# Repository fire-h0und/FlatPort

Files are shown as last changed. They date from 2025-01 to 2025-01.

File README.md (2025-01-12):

# FlatPort
Teensy 2.0 Risc-V dropin Arduino promicro lookalike with special features. The chip I used is [GD32 VF 103 CBT6](https://www.gigadevice.com/product/mcu/mcus-product-selector/gd32vf103cbt6) from Giga Device. 

It has a in-plane Type-C USB receptacle - it does not show much but it doubles as a full featured Type-C port - in this case a reversible USB 2.0 spec port only.

It also features in-plane Reset and Boot0 tasters - they are shorted by touching with a pointy conductive/metal object.<br>
  Do note they are not to be touched mutually by a same metal object: one shorts pin Boot0 to ground the other pulls the reset pin to Vcc.<br>
  In effect this means one of the contacts is gound and the other is Vcc - shorting them mutually would blow the fuse!

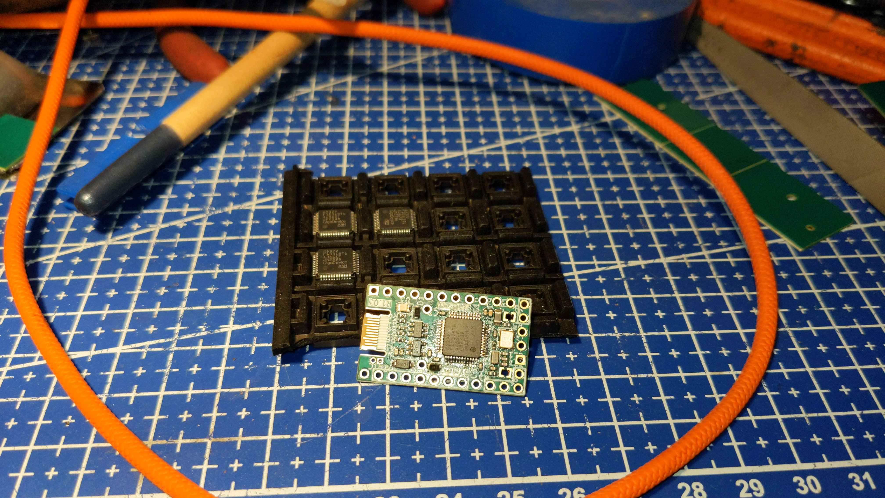
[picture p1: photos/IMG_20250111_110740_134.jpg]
Top view assembled A top view of the FlatPort R1.03


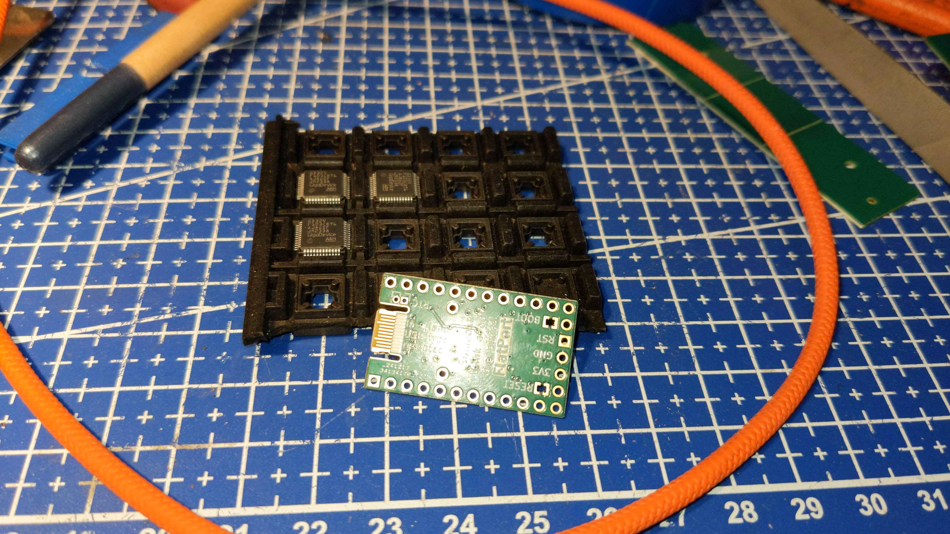
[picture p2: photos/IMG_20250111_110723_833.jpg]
Bottom View A clumsy lit back view of the FlatPort


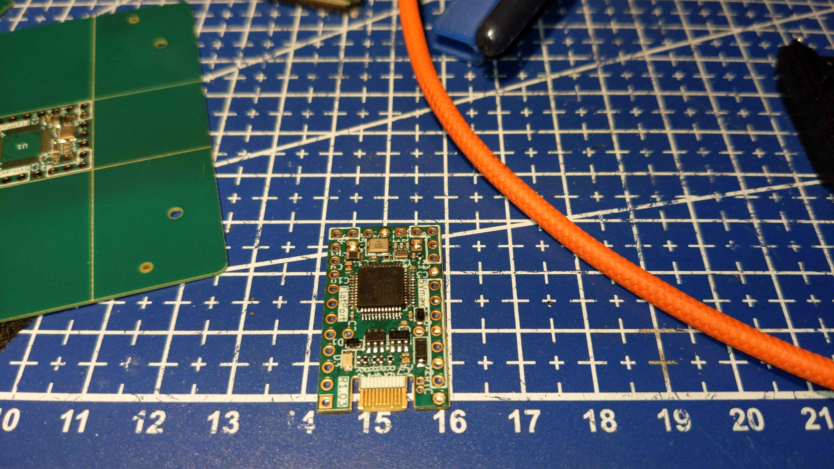
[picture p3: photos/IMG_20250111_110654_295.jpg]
View of the FlatPort Lying flat on the deskpad


I picked to make this project for the alleged compatibility with QMK firmware - to be a future keyboard daughter board.
As I get to that point expect more updates here, it is on my ever growing TODO list :o}

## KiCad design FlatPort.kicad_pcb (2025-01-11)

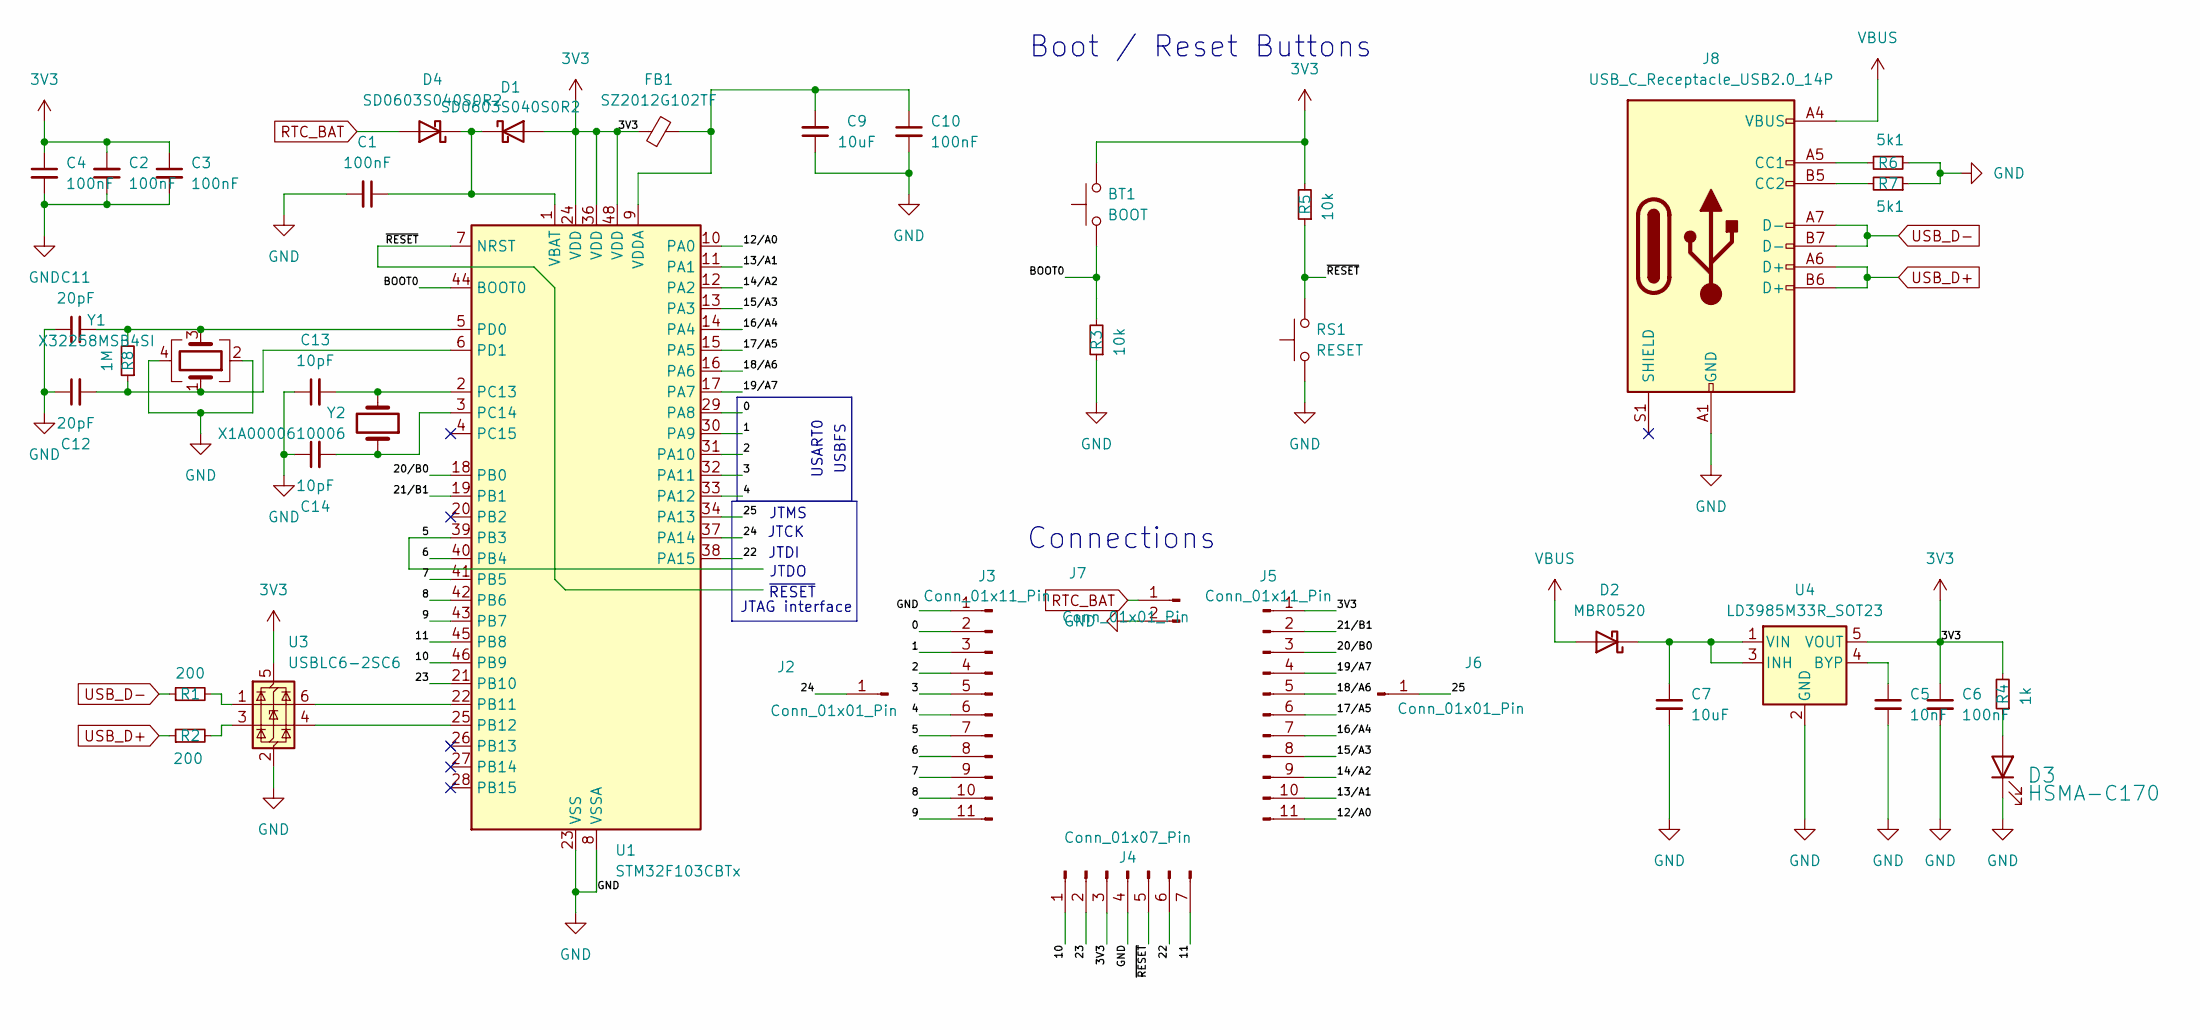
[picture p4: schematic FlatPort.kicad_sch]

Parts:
BT1: BOOT; Switch_Hole_1.0mm
C1, C2, C3, C4, C6, C10: 100nF; C_0402_1005Metric
C5: 10nF; C_0402_1005Metric
C7, C9: 10uF; C_0402_1005Metric
C11, C12: 20pF; C_0402_1005Metric
C13, C14: 10pF; C_0402_1005Metric
D1, D4: SD0603S040S0R2; D_0603_1608Metric
D2: MBR0520; D_SOD-123
D3: HSMA-C170; LED_0805_2012Metric
FB1: SZ2012G102TF; L_0805_2012Metric; LCSC Part# C1002
J2, J6: Conn_01x01_Pin; PinHeader_1x01_P2.54mm_Vertical
J3, J5: Conn_01x11_Pin; PinHeader_1x11_P2.54mm_Vertical
J4: Conn_01x07_Pin; PinHeader_1x07_P2.54mm_Vertical
J7: Conn_01x01_Pin; PinHeader_1x02_P1.27mm_Vertical
J8: USB_C_Receptacle_USB2.0_14P; TypeC_PCB_cutout
R1, R2: 200; R_0402_1005Metric
R3, R5: 10k; R_0402_1005Metric
R4: 1k; R_0402_1005Metric
R6, R7: 5k1; R_0402_1005Metric
R8: 1M; R_0402_1005Metric
RS1: RESET; Switch_Hole_1.0mm
U1: STM32F103CBTx; LQFP-48_7x7mm_P0.5mm
U3: USBLC6-2SC6; SOT-23-6
U4: LD3985M33R_SOT23; SOT-23-5
Y1: X32258MSB4SI; Crystal_SMD_3225-4Pin_3.2x2.5mm
Y2: X1A0000610006; Crystal_SMD_2012-2Pin_2.0x1.2mm

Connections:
3V3: BT1.2, C2.2, C3.1, C4.1, C6.1, D1.2 (A), FB1.1, J4.3, J5.1, R4.2, R5.2, U1.24 (VDD), U1.36 (VDD), U1.48 (VDD), U3.5 (VBUS), U4.5 (VOUT)
/0: J3.2, U1.29 (PA8)
/1: J3.3, U1.30 (PA9)
/2: J3.4, U1.31 (PA10)
/3: J3.5, U1.32 (PA11)
/4: J3.6, U1.33 (PA12)
/5: J3.7, U1.39 (PB3)
/6: J3.8, U1.40 (PB4)
/7: J3.9, U1.41 (PB5)
/8: J3.10, U1.42 (PB6)
/9: J3.11, U1.43 (PB7)
/10: J4.1, U1.46 (PB9)
/11: J4.7, U1.45 (PB8)
/12/A0: J5.11, U1.10 (PA0)
/13/A1: J5.10, U1.11 (PA1)
/14/A2: J5.9, U1.12 (PA2)
/15/A3: J5.8, U1.13 (PA3)
/16/A4: J5.7, U1.14 (PA4)
/17/A5: J5.6, U1.15 (PA5)
/18/A6: J5.5, U1.16 (PA6)
/19/A7: J5.4, U1.17 (PA7)
/20/B0: J5.3, U1.18 (PB0)
/21/B1: J5.2, U1.19 (PB1)
/22: J4.6, U1.38 (PA15)
/23: J4.2, U1.21 (PB10)
/24: J2.1, U1.37 (PA14)
/25: J6.1, U1.34 (PA13)
/BOOT0: BT1.1, R3.2, U1.44 (BOOT0)
/~RESET: J4.5, R5.1, RS1.2, U1.7 (NRST)
GND: C1.2, C2.1, C3.2, C4.2, C5.2, C6.2, C7.2, C9.1, C10.2, C11.1, C12.1, C13.1, C14.1, D3.1 (K), J3.1, J4.4, J7.2, J8.A1 (GND), J8.A12 (GND), J8.B1 (GND), J8.B12 (GND), R3.1, R6.1, R7.1, RS1.1, U1.8 (VSSA), U1.23 (VSS), U1.35 (VSS), U1.47 (VSS), U3.2 (GND), U4.2 (GND), Y1.2, Y1.4
unnamed: C1.1, D1.1 (K), D4.1 (K), U1.1 (VBAT)
unnamed: C7.1, D2.1 (K), U4.1 (VIN), U4.3 (INH)
unnamed: D3.2 (A), R4.1
unnamed: J8.A5 (CC1), R6.2
unnamed: J8.B5 (CC2), R7.2
unnamed: R1.2, U3.1 (I/O1)
unnamed: R2.2, U3.3 (I/O2)
unnamed: U1.22 (PB11), U3.6 (I/O1)
unnamed: U1.25 (PB12), U3.4 (I/O2)
unnamed: C13.2, U1.2 (PC13), Y2.2
unnamed: C14.2, U1.3 (PC14), Y2.1
unnamed: C11.2, R8.2, U1.5 (PD0), Y1.3
unnamed: C12.2, R8.1, U1.6 (PD1), Y1.1
unnamed: C9.2, C10.1, FB1.2, U1.9 (VDDA)
unnamed: C5.1, U4.4 (BYP)
RTC_BAT: D4.2 (A), J7.1
USB_D+: J8.A6 (D+), J8.B6 (D+), R2.1
USB_D-: J8.A7 (D-), J8.B7 (D-), R1.1
VBUS: D2.2 (A), J8.A4 (VBUS), J8.A9 (VBUS), J8.B4 (VBUS), J8.B9 (VBUS)

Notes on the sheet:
Boot / Reset Buttons
Connections
JTMS
USBFS
JTCK
~{RESET}
USART0
JTAG interface
JTDI
JTDO

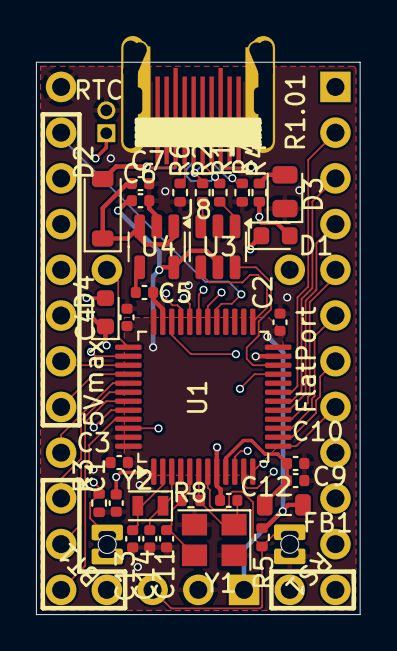
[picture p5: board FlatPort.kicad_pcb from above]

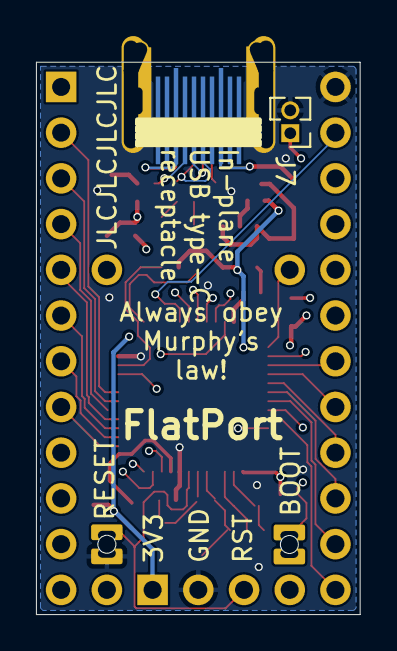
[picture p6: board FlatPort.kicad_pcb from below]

Board: 4 copper layers, 18.0 x 30.7 mm, 40 parts (6 on the bottom side), 49 nets.

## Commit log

2025-01-11 The R1.03 source files that actually had been sent for production
    This is the first build release
    [FlatPort.kicad_pcb, FlatPort.kicad_sch]
2025-01-11 i think this file has the missing footprints
2025-01-11 The photos of the FlatPort
    Manufactured at JLCPCB and hand soldered the MCU in my shop
